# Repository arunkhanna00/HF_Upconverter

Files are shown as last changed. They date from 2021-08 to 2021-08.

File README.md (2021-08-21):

# Upconverter
An upconverter used to convert HF signals (3-33 MHz) to 125+MHz that can be recognized by an RTL-SDR

Inspired by [Nooelectric Ham It Up](https://www.nooelec.com/store/ham-it-up.html)

Upconverter

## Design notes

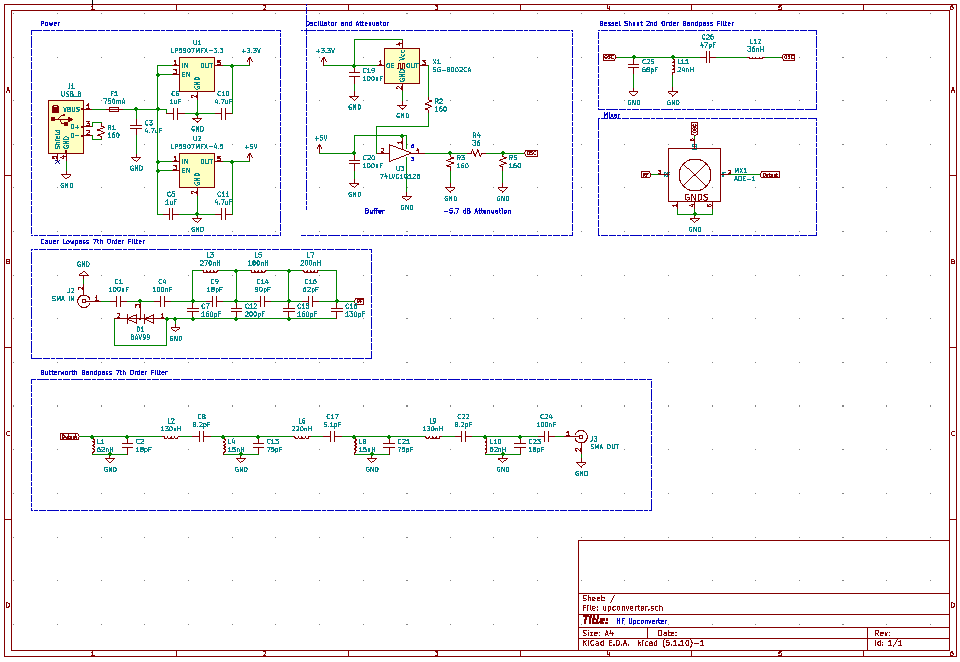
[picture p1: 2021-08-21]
schematic/shematic.PNG

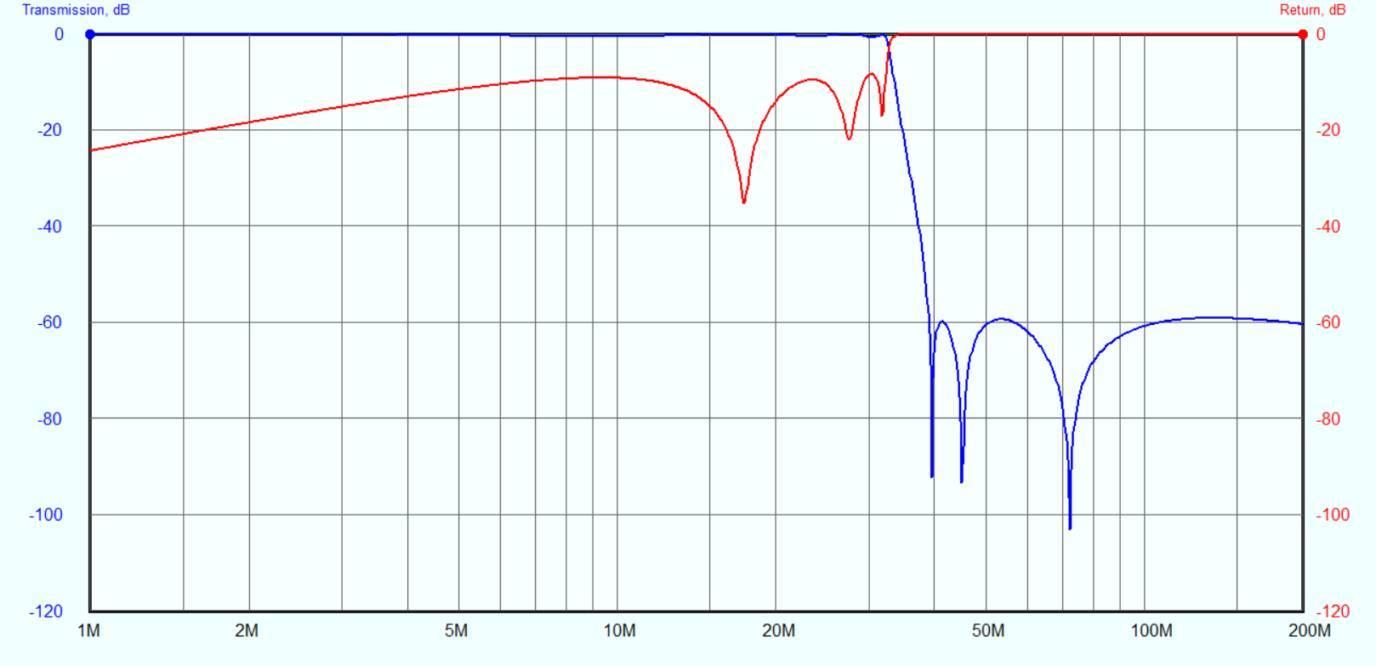
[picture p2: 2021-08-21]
filters/cauer_lowpass.PNG

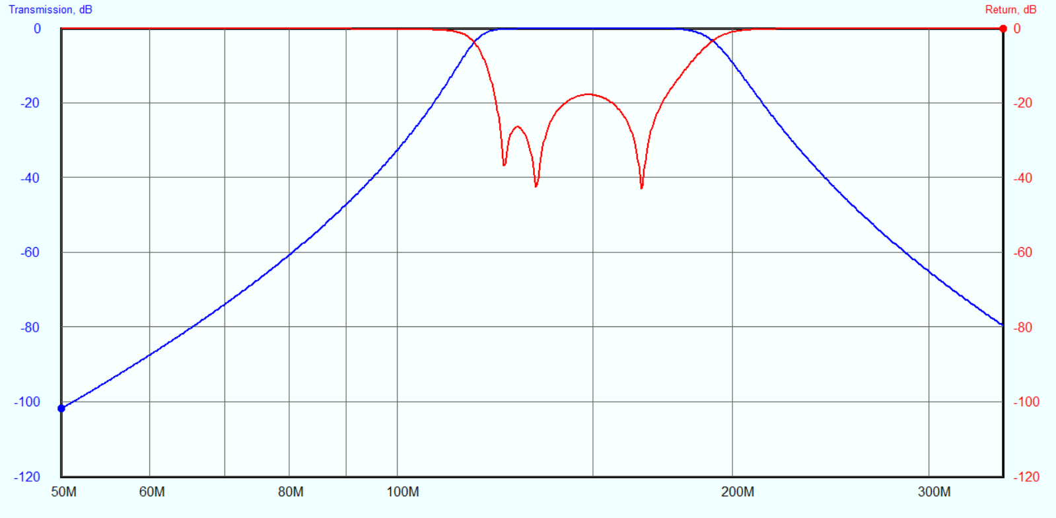
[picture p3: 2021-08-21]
filters/butterworth_bandpass.PNG

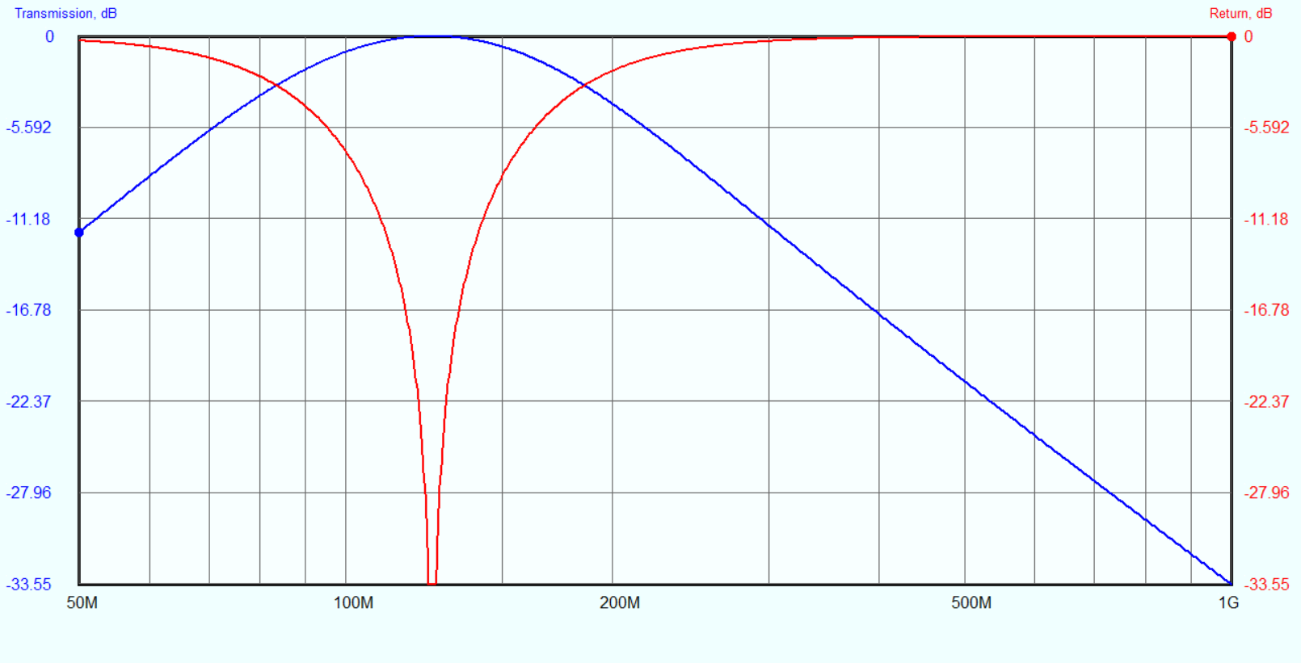
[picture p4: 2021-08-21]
filters/bessel_bandpass.PNG

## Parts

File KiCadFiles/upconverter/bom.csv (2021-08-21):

Id | Designator | Package | Quantity | Designation | Supplier and ref
1 | J2 | SMA_Samtec_SMA-J-P-X-ST-EM1_EdgeMount | 1 | SMA IN
2 | J3 | SMA_Samtec_SMA-J-P-X-ST-EM1_EdgeMount | 1 | SMA OUT
3 | C20,C1,C4,C19,C24 | C_0805_2012Metric | 5 | 100nF
4 | C2,C9,C23 | C_0805_2012Metric | 3 | 18pF
5 | C3,C10,C11 | C_0805_2012Metric | 3 | 4.7uF
6 | C5,C6 | C_0805_2012Metric | 2 | 1uF
7 | C7,C15 | C_0805_2012Metric | 2 | 160pF
8 | C8,C22 | C_0805_2012Metric | 2 | 8.2pF
9 | C12 | C_0805_2012Metric | 1 | 200pF
10 | C13,C21 | C_0805_2012Metric | 2 | 75pF
11 | C14 | C_0805_2012Metric | 1 | 90pF
12 | C16 | C_0805_2012Metric | 1 | 62pF
13 | C17 | C_0805_2012Metric | 1 | 5.1pF
14 | C18 | C_0805_2012Metric | 1 | 130pF
15 | C25 | C_0805_2012Metric | 1 | 68pF
16 | C26 | C_0805_2012Metric | 1 | 47pF
17 | D1 | SOT-23 | 1 | BAV99
18 | F1 | Fuse_1206_3216Metric_Castellated | 1 | 750mA
19 | J1 | USB_B_OST_USB-B1HSxx_Horizontal | 1 | USB_B
20 | L1,L10 | L_0805_2012Metric | 2 | 62nH
21 | L2,L9 | L_0805_2012Metric | 2 | 130nH
22 | L3 | L_0805_2012Metric | 1 | 270nH
23 | L4,L8 | L_0805_2012Metric | 2 | 15nH
24 | L5 | L_0805_2012Metric | 1 | 180nH
25 | L6 | L_0805_2012Metric | 1 | 220nH
26 | L7 | L_0805_2012Metric | 1 | 200nH
27 | L11 | L_0805_2012Metric | 1 | 24nH
28 | L12 | L_0805_2012Metric | 1 | 36nH
29 | MX1 | CD636 | 1 | ADE-1
30 | R1,R2,R3,R5 | R_0805_2012Metric | 4 | 160
31 | R4 | R_0805_2012Metric | 1 | 36
32 | U1 | SOT-23-5 | 1 | LP5907MFX-3.3
33 | U2 | SOT-23-5 | 1 | LP5907MFX-4.5
34 | U3 | SOT-23-5 | 1 | 74LVC1G126
35 | X1 | Oscillator_SMD_SeikoEpson_SG8002CA-4Pin_7.0x5.0mm | 1 | SG-8002CA

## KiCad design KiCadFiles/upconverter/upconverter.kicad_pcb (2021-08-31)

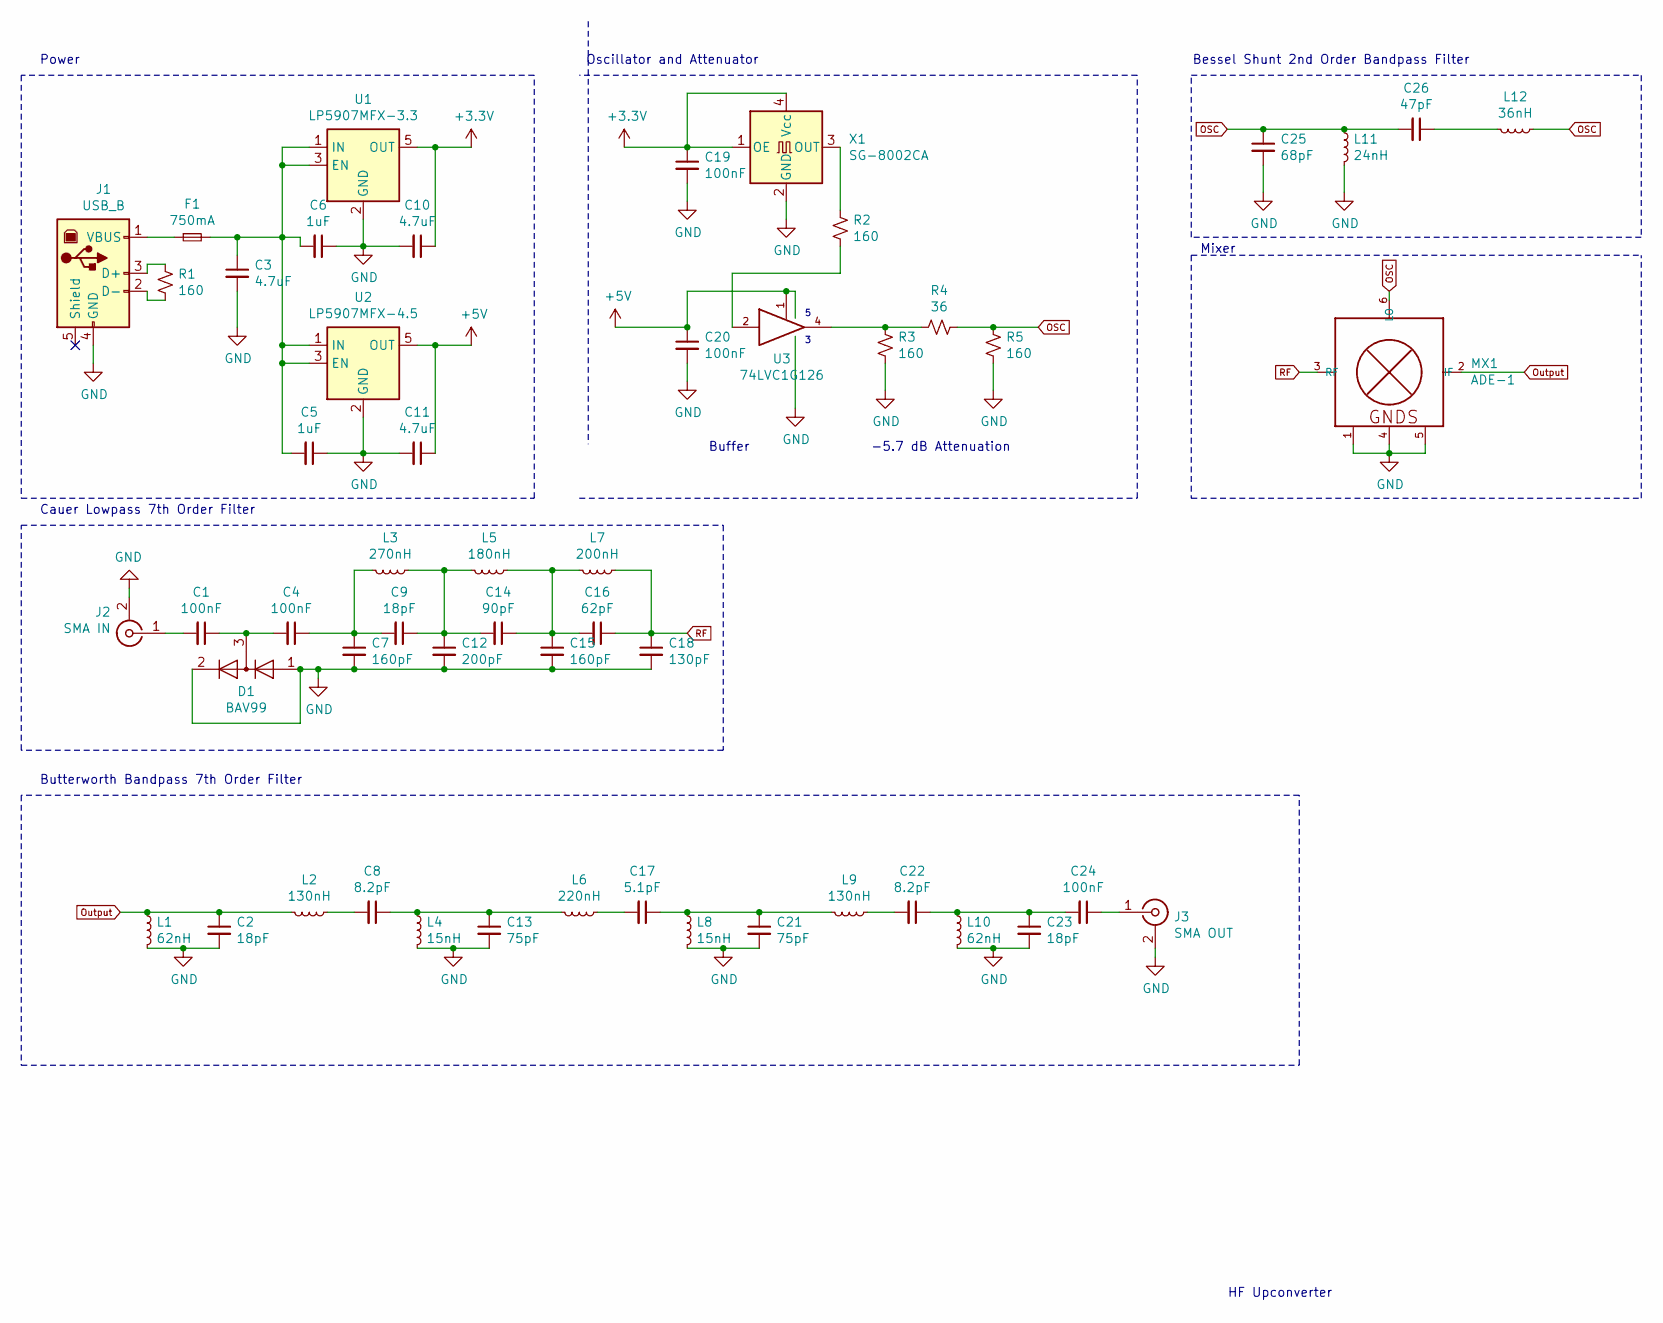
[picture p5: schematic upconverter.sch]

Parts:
C1, C4, C19, C20, C24: 100nF; C_0805_2012Metric
C2, C9, C23: 18pF; C_0805_2012Metric
C3, C10, C11: 4.7uF; C_0805_2012Metric
C5, C6: 1uF; C_0805_2012Metric
C7, C15: 160pF; C_0805_2012Metric
C8, C22: 8.2pF; C_0805_2012Metric
C12: 200pF; C_0805_2012Metric
C13, C21: 75pF; C_0805_2012Metric
C14: 90pF; C_0805_2012Metric
C16: 62pF; C_0805_2012Metric
C17: 5.1pF; C_0805_2012Metric
C18: 130pF; C_0805_2012Metric
C25: 68pF; C_0805_2012Metric
C26: 47pF; C_0805_2012Metric
D1: BAV99; SOT-23
F1: 750mA; Fuse_1206_3216Metric_Castellated
J1: USB_B; USB_B_OST_USB-B1HSxx_Horizontal
J2: SMA IN; SMA_Samtec_SMA-J-P-X-ST-EM1_EdgeMount
J3: SMA OUT; SMA_Samtec_SMA-J-P-X-ST-EM1_EdgeMount
L1, L10: 62nH; L_0805_2012Metric
L2, L9: 130nH; L_0805_2012Metric
L3: 270nH; L_0805_2012Metric
L4, L8: 15nH; L_0805_2012Metric
L5: 180nH; L_0805_2012Metric
L6: 220nH; L_0805_2012Metric
L7: 200nH; L_0805_2012Metric
L11: 24nH; L_0805_2012Metric
L12: 36nH; L_0805_2012Metric
MX1: ADE-1; CD636
R1, R2, R3, R5: 160; R_0805_2012Metric
R4: 36; R_0805_2012Metric
U1: LP5907MFX-3.3; SOT-23-5
U2: LP5907MFX-4.5; SOT-23-5
U3: 74LVC1G126; SOT-23-5
X1: SG-8002CA; Oscillator_SMD_SeikoEpson_SG8002CA-4Pin_7.0x5.0mm

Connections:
+3V3: C10.1, C19.1, U1.5 (OUT), X1.1 (OE), X1.4 (Vcc)
+5V: C11.1, C20.1, U2.5 (OUT), U3.1, U3.5 (VCC)
GND: C2.2, C3.2, C5.1, C6.1, C7.2, C10.2, C11.2, C12.2, C13.2, C15.2, C18.2, C19.2, C20.2, C21.2, C23.2, C25.2, D1.1 (K), D1.2 (A), J1.4 (GND), J2.2 (Ext), J3.2 (Ext), L1.2, L4.2, L8.2, L10.2, L11.2, MX1.1, MX1.4, MX1.5, R3.2, R5.2, U1.2 (GND), U2.2 (GND), U3.3 (GND), X1.2 (GND)
unnamed: C1.1, C4.2, D1.3 (K)
unnamed: C1.2, J2.1 (In)
unnamed: C3.1, C5.2, C6.2, F1.2, U1.1 (IN), U1.3 (EN), U2.1 (IN), U2.3 (EN)
unnamed: C4.1, C7.1, C9.2, L3.2
unnamed: C8.2, L2.1
unnamed: C9.1, C12.1, C14.2, L3.1, L5.2
unnamed: C8.1, C13.1, L4.1, L6.2
unnamed: C14.1, C15.1, C16.2, L5.1, L7.2
unnamed: C17.1, C21.1, L8.1, L9.2
unnamed: C17.2, L6.1
unnamed: C22.1, C23.1, C24.2, L10.1
unnamed: C22.2, L9.1
unnamed: C24.1, J3.1 (In)
unnamed: C26.1, L12.2
unnamed: F1.1, J1.1 (VBUS)
unnamed: J1.2 (D-), R1.2
unnamed: J1.3 (D+), R1.1
unnamed: R2.1, X1.3 (OUT)
unnamed: R2.2, U3.2
unnamed: R3.1, R4.2, U3.4
OSC: C25.1, C26.2, L11.1, L12.1, MX1.6 (LO), R4.1, R5.1
Output: C2.1, L1.1, L2.2, MX1.2 (IF)
RF: C16.1, C18.1, L7.1, MX1.3 (RF)

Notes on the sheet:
HF Upconverter
Power
Oscillator and Attenuator
-5.7 dB Attenuation
Mixer
Buffer
Cauer Lowpass 7th Order Filter
Butterworth Bandpass 7th Order Filter
Bessel Shunt 2nd Order Bandpass Filter

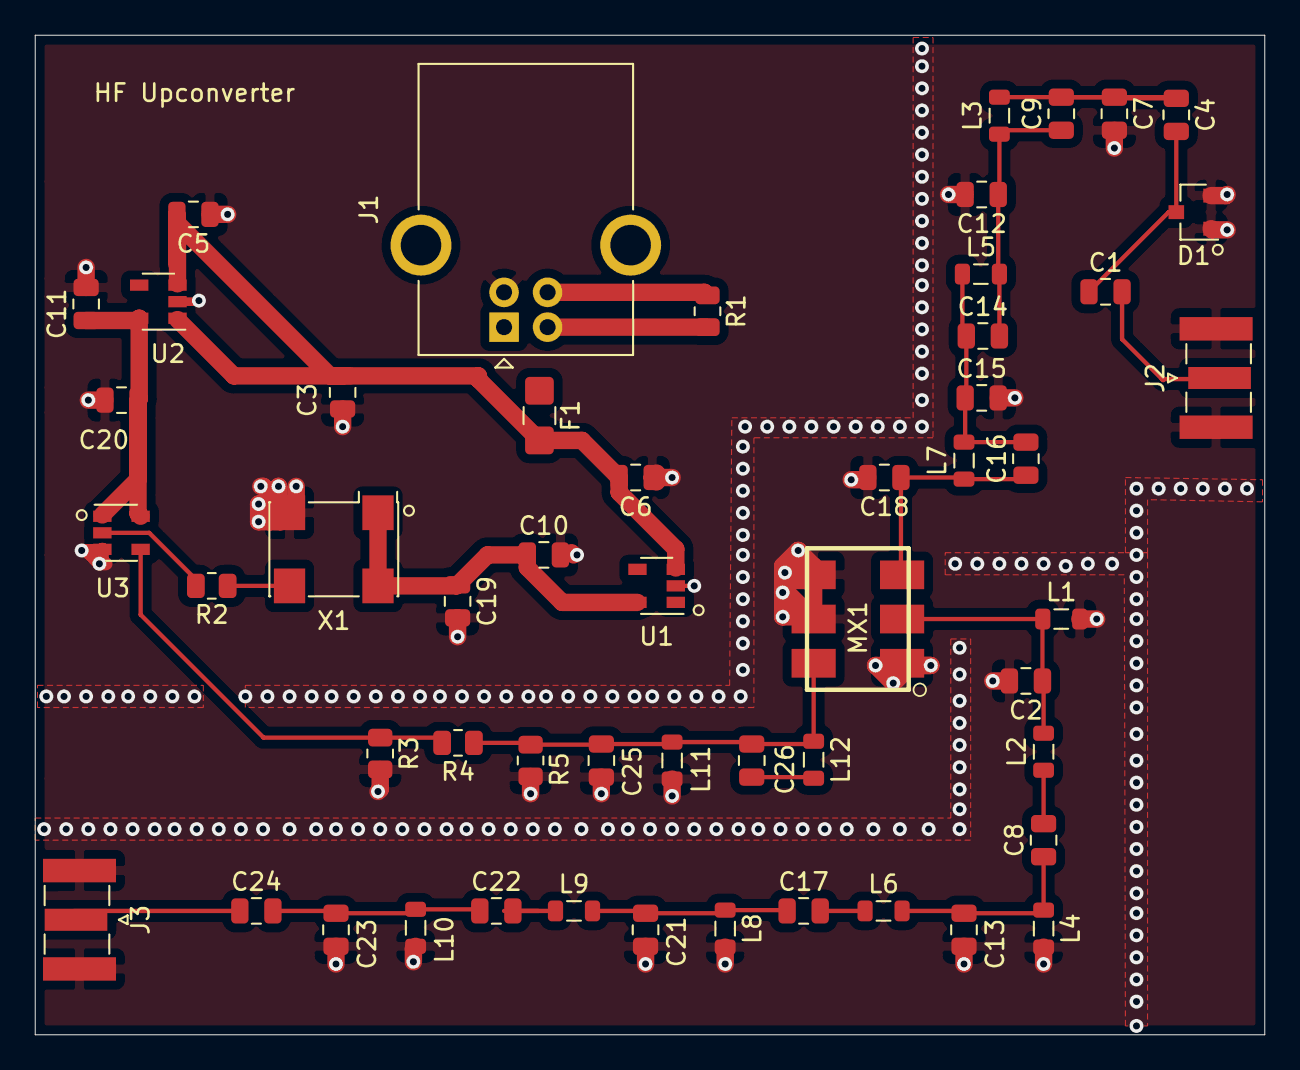
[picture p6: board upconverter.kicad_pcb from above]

Board: 2 copper layers, 70.6 x 57.4 mm, 53 parts (0 on the bottom side), 26 nets.

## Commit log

2021-08-21 Add gerber files
    [upconverter-B_Cu.gbr, upconverter-B_Mask.gbr, upconverter-B_Paste.gbr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]
2021-08-21 Add schematic
    [upconverter.sch]
2021-08-21 s-params of filters
    Used Elsie to calculate these
